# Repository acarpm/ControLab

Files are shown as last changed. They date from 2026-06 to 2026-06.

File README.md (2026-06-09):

## Fonctionnement de la carte ControlLab

### Vue d'ensemble

ControlLab est une carte de contrôle d'accès NFC.
Son rôle est de lire un badge NFC présenté par un utilisateur,
de vérifier son autorisation, puis de signaler le résultat
(LED + buzzer). 

```
Badge NFC
    │
    ▼
┌─────────┐    I2C     ┌──────────────────┐
│  PN532  │ ────────▶  │  ESP32-S3-MINI-1 │
│  (NFC)  │            │                  │
└─────────┘            │  • Lecture UID   │
                       │  • Vérification  │
┌─────────┐            │  • Wi-Fi / BLE   │
│  OLED   │ ◀───I2C─── │                  │
└─────────┘            └──────────────────┘
                              │        │
                         GPIO38    GPIO46
                              │        │
                        NeoPixels   Buzzer
```
                
### 1. Alimentation

La carte est alimentée via USB-C (VBUS = 5V).

- **Polyfuse F1** : protection contre les surintensités
- **TVS D6** : protection contre les surtensions ESD sur VBUS
- **AMS1117-3.3** : régulateur linéaire qui abaisse le 5V en 3.3V
  pour alimenter l'ESP32, le PN532, l'OLED et le buzzer.

USB-C (5V VBUS)
    │
   [F1] Polyfuse
    │
   [D6] TVS (protection ESD)
    │
[AMS1117-3.3] ──▶ 3V3 (ESP32, PN532, OLED, Buzzer)

### 2. Lecture NFC (PN532)

Le module PN532 est le lecteur NFC de la carte.
Il communique avec l'ESP32 via **I2C** (SDA = GPIO10, SCL = GPIO11).

Quand un badge ( tag NFC) est présenté :
1. Le PN532 détecte le champ RF et lit l'**UID** du badge
2. Il transmet l'UID à l'ESP32 via I2C

Les lignes RSTPD (GPIO11) et IRQ (GPIO10) permettent
à l'ESP32 de réinitialiser le PN532 et d'être notifié
d'une nouvelle lecture sans polling continu.

### 3. Signalisation utilisateur

#### LEDs NeoPixel (GPIO38)
3 LEDs RGB WS2812 montées en chaîne DIN → DOUT.
Elles indiquent l'état de la lecture :

| Couleur | Signification |
|---|---|
| 🟢 Vert | Accès autorisé |
| 🔴 Rouge | Accès refusé |
| 🔵 Bleu | En attente / veille |

#### Buzzer (GPIO46)
Buzzer actif 3.3V piloté via GPIO46 (R7 = 200Ω en série).
- 1 bip court : badge reconnu
- 2 bips : accès refusé

#### Écran OLED (J2 — I2C)
Affiche le nom de l'utilisateur ou le statut de la carte.
Lignes I2C partagées avec le PN532 .
Pull-ups 4.7kΩ maintenus à 3.3V (R5, R6).

### 5. Programmation

La carte se programme via **USB natif** (GPIO18/19 — USB D-/D+).
Aucun adaptateur UART externe nécessaire.
Pour passer en mode flash :
1. Maintenir **BOOT** (SW2 — GPIO0)
2. Appuyer sur **RESET** (SW1)
3. Relâcher BOOT

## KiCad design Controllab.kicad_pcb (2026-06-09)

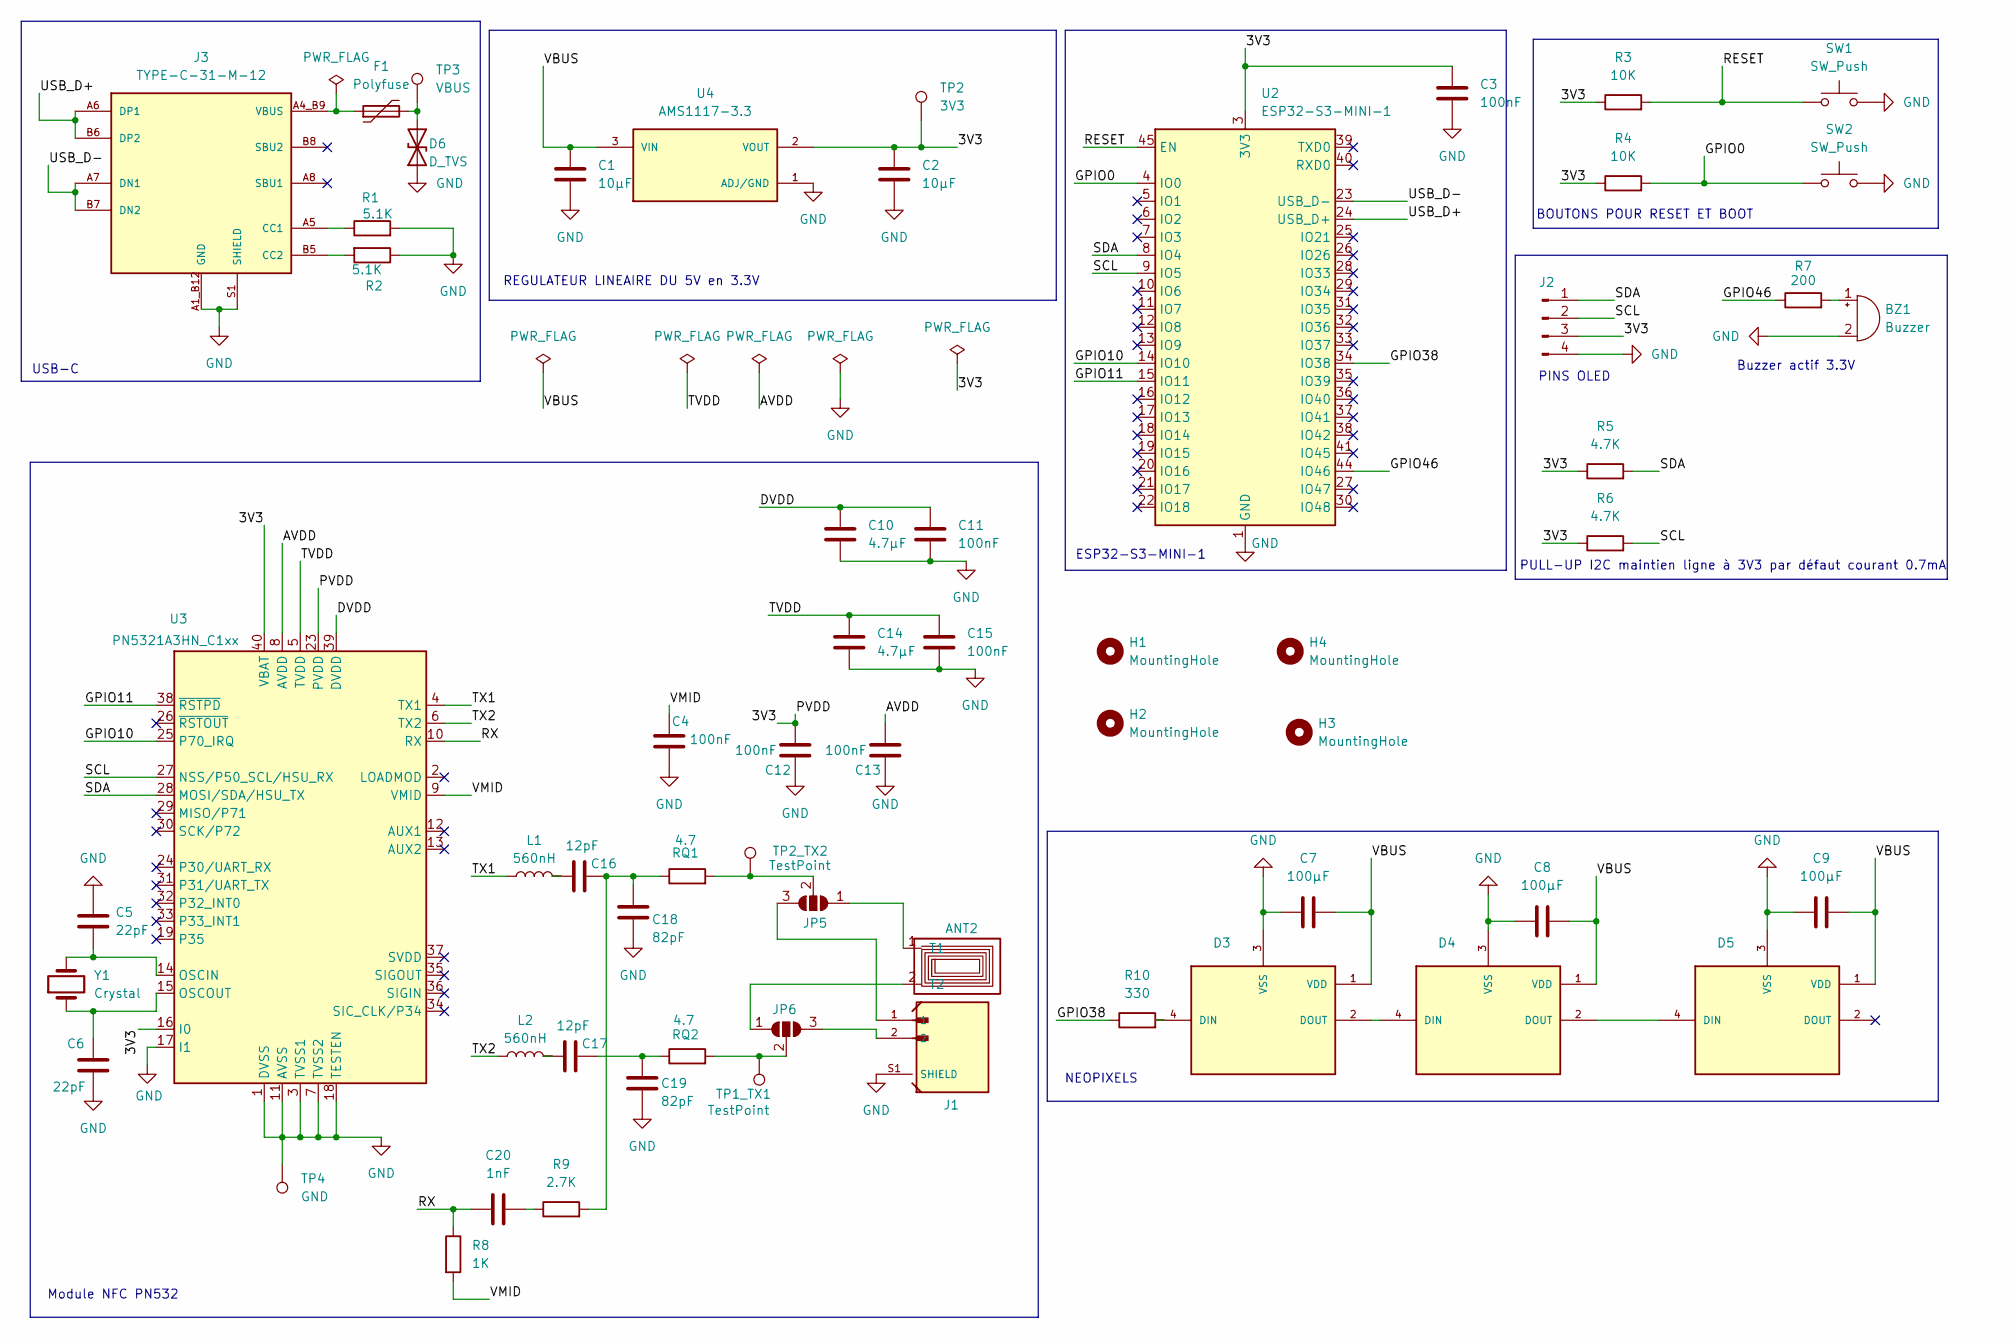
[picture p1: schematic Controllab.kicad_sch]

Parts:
ANT2: 13.56MHz_NFC_Antenna_Square; NFC_35x20_N5_NXP_PN532
BZ1: Buzzer; Buzzer_12x9.5RM7.6
C1, C2: 10µF; C_0603_1608Metric
C3, C4, C11, C12, C13, C15: 100nF; C_0603_1608Metric
C5, C6: 22pF; C_0603_1608Metric
C7, C8, C9: 100µF; C_0603_1608Metric
C10, C14: 4.7µF; C_0603_1608Metric
C16, C17: 12pF; C_0603_1608Metric
C18, C19: 82pF; C_0603_1608Metric
C20: 1nF; C_0603_1608Metric
D3, D4, D5: 2758; SOL320P540X170-4N; PARTREV 01
D6: D_TVS; D_SOD-123
F1: Polyfuse; Fuse_1206_3216Metric
H1, H2, H3, H4: MountingHole; MountingHole_2.1mm
J1: BM02B-GHS-TBT_LF__SN__N_; JST_BM02B-GHS-TBT_LF__SN__N_
J2: PinHeader_1x04_P2.54mm_Vertical
J3: TYPE-C-31-M-12; HRO_TYPE-C-31-M-12; PARTREV 2020.12.08
JP5, JP6: SolderJumper_3_Open; SolderJumper-3_P1.3mm_Open_Pad1.0x1.5mm
L1, L2: 560nH; L_0603_1608Metric
R1, R2: 5.1K; R_0603_1608Metric
R3, R4: 10K; R_0603_1608Metric
R5, R6: 4.7K; R_0603_1608Metric
R7: 200; R_0603_1608Metric
R8: 1K; R_0603_1608Metric
R9: 2.7K; R_0603_1608Metric
R10: 330; R_0603_1608Metric
RQ1, RQ2: 4.7; R_0603_1608Metric
SW1, SW2: SW_Push; SW_SPST_PTS645Sx43SMTR92
TP1_TX1, TP2_TX2: TestPoint; TestPoint_Pad_D1.0mm
TP2: 3V3; TestPoint_Pad_D1.0mm
TP3: VBUS; TestPoint_Pad_D1.0mm
TP4: GND; TestPoint_Pad_D1.0mm
U2: ESP32-S3-MINI-1; XCVR_ESP32-S3-MINI-1-N8
U3: PN5321A3HN_C1xx; HVQFN-40-1EP_6x6mm_P0.5mm_EP4.1x4.1mm
U4: AMS1117-3.3; SOT229P700X180-4N; PARTREV NA
Y1: Crystal; Crystal_SMD_3225-4Pin_3.2x2.5mm

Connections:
/3V3: C2.1, C3.1, C12.1, J2.3, R3.1, R4.1, R5.1, R6.1, TP2.1 (1_1), U2.3 (3V3), U3.16 (I0), U3.23 (PVDD), U3.40 (VBAT), U4.2 (VOUT)
/AVDD: C13.1, U3.8 (AVDD)
/DVDD: C10.2, C11.2, U3.39 (DVDD)
/GPIO0: R4.2, SW2.1, U2.4 (IO0)
/GPIO10: U2.14 (IO10), U3.25 (P70_IRQ)
/GPIO11: U2.15 (IO11), U3.38 (~RSTPD)
/GPIO38: R10.1, U2.34 (IO38)
/GPIO46: R7.1, U2.44 (IO46)
/RESET: R3.2, SW1.1, U2.45 (EN)
/RX: C20.1, R8.1, U3.10 (RX)
/SCL: J2.2, R6.2, U2.9 (IO5), U3.27 (NSS/P50_SCL/HSU_RX)
/SDA: J2.1, R5.2, U2.8 (IO4), U3.28 (MOSI/SDA/HSU_TX)
/TVDD: C14.2, C15.2, U3.5 (TVDD)
/TX1: L1.1, U3.4 (TX1)
/TX2: L2.1, U3.6 (TX2)
/USB_D+: J3.A6 (DP1), J3.B6 (DP2), U2.24 (USB_D+)
/USB_D-: J3.A7 (DN1), J3.B7 (DN2), U2.23 (USB_D-)
/VMID: C4.1, R8.2, U3.9 (VMID)
GND: BZ1.2 (-), C1.2, C2.2, C3.2, C4.2, C5.2, C6.2, C7.1, C8.1, C9.1, C10.1, C11.1, C12.2, C13.2, C14.1, C15.1, C18.2, C19.2, D3.3 (VSS), D4.3 (VSS), D5.3 (VSS), D6.1 (A1), J1.S1 (SHIELD), J1.S2 (SHIELD), J2.4, J3.A1_B12 (GND), J3.S1 (SHIELD), R1.2, R2.1, SW1.2, SW2.2, TP4.1 (1_1), U2.1 (GND), U2.2 (GND), U2.42 (GND), U2.43 (GND), U2.46 (GND), U2.47 (GND), U2.48 (GND), U2.49 (GND), U2.50 (GND), U2.51 (GND), U2.52 (GND), U2.53 (GND), U2.54 (GND), U2.55 (GND), U2.56 (GND), U2.57 (GND), U2.58 (GND), U2.59 (GND), U2.60 (GND), U2.61 (GND), U2.62 (GND), U2.63 (GND), U2.64 (GND), U2.65 (GND), U3.1 (DVSS), U3.3 (TVSS1), U3.7 (TVSS2), U3.11 (AVSS), U3.17 (I1), U3.18 (TESTEN), U3.41 (AVSS), U4.1 (ADJ/GND); also elsewhere on the board
unnamed: ANT2.1 (T1), JP5.1 (A)
unnamed: ANT2.2 (T2), JP6.1 (A)
unnamed: BZ1.1 (+), R7.2
unnamed: C16.1, L1.2
unnamed: C16.2, C18.1, R9.2, RQ1.1
unnamed: C17.1, L2.2
unnamed: C17.2, C19.1, RQ2.1
unnamed: C20.2, R9.1
unnamed: D3.4 (DIN), R10.2
unnamed: D3.2 (DOUT), D4.4 (DIN)
unnamed: D4.2 (DOUT), D5.4 (DIN)
unnamed: D6.2 (A2), F1.2, TP3.1 (1_1)
unnamed: J3.A5 (CC1), R1.1
unnamed: J3.B5 (CC2), R2.2
unnamed: J1.1, JP5.3 (B)
unnamed: JP5.2 (C), RQ1.2, TP2_TX2.1 (1_1)
unnamed: J1.2, JP6.3 (B)
unnamed: JP6.2 (C), RQ2.2, TP1_TX1.1 (1_1)
unnamed: C5.1, U3.14 (OSCIN), Y1.2
unnamed: C6.1, U3.15 (OSCOUT), Y1.1

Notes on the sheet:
Buzzer actif 3.3V
PINS OLED
NEOPIXELS
Module NFC PN532
ESP32-S3-MINI-1
REGULATEUR LINEAIRE DU 5V en 3.3V
USB-C
BOUTONS POUR RESET ET BOOT
PULL-UP I2C maintien ligne à 3V3 par défaut courant 0.7mA

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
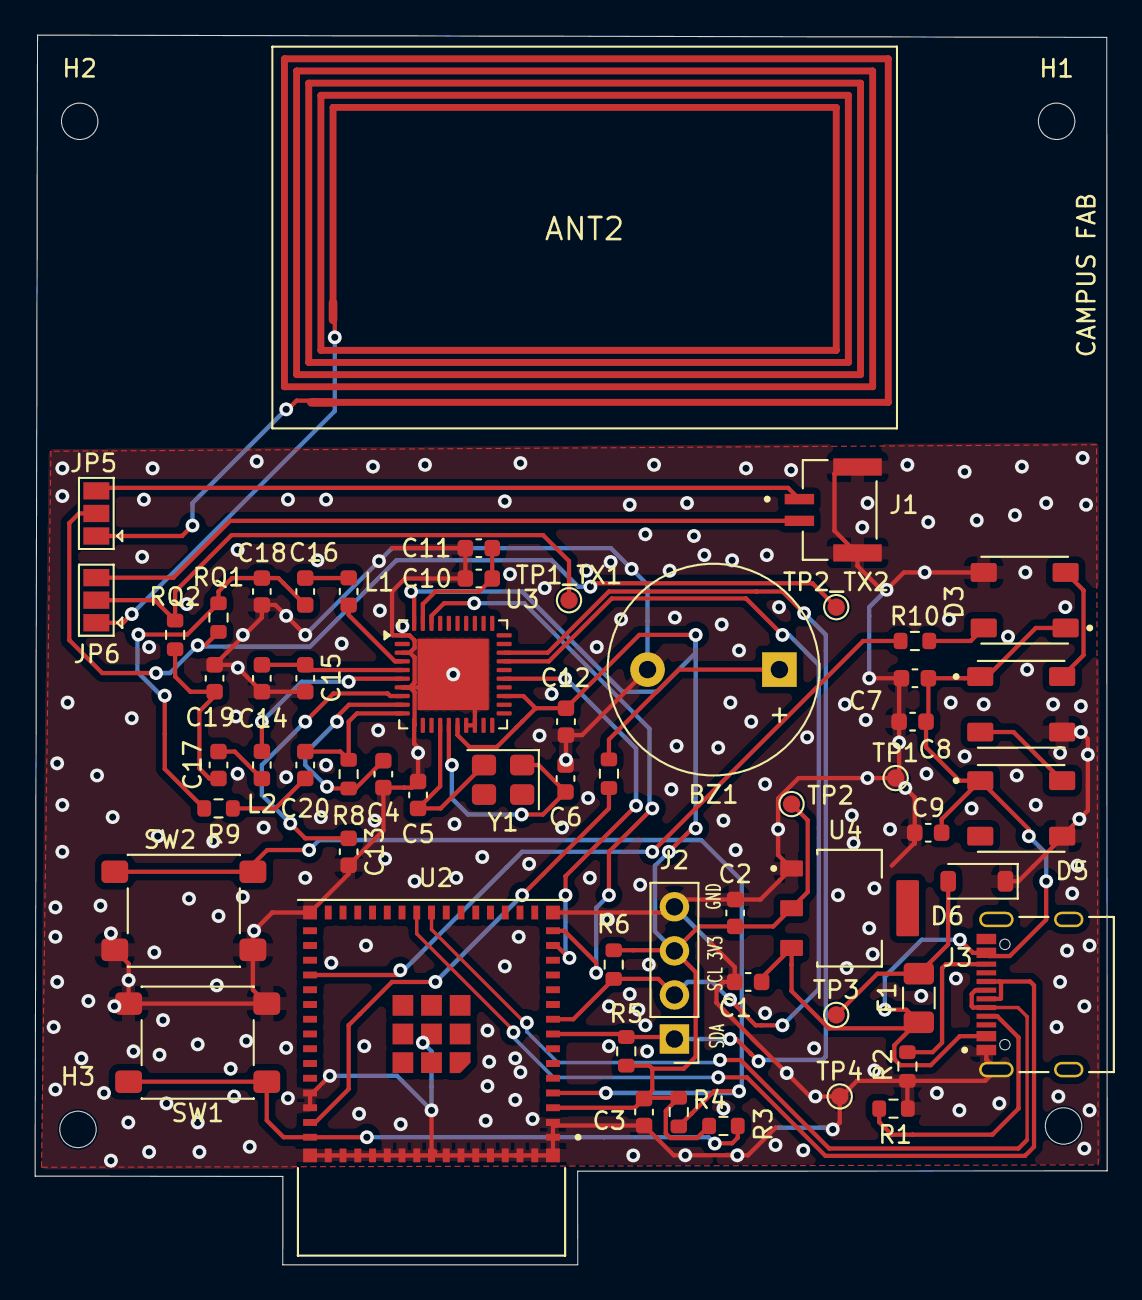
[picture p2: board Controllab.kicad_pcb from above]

Board: 2 copper layers, 61.8 x 70.9 mm, 62 parts (0 on the bottom side), 40 nets.

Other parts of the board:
TP1: GND; TestPoint_Pad_D1.0mm

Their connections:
GND: TP1.1 (1_1); also elsewhere on the board

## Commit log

2026-06-08 La carte est prete
    [Controllab.kicad_pcb, Controllab.kicad_sch]
2026-06-08 ajout des noms sur la carte
    [Controllab.kicad_pcb, Controllab.kicad_sch]
2026-06-08 Ajout des noms sur le connecteur de l'oled
    [Controllab.kicad_pcb]
2026-06-09 Small DRC fix
    [Controllab.kicad_pcb]
